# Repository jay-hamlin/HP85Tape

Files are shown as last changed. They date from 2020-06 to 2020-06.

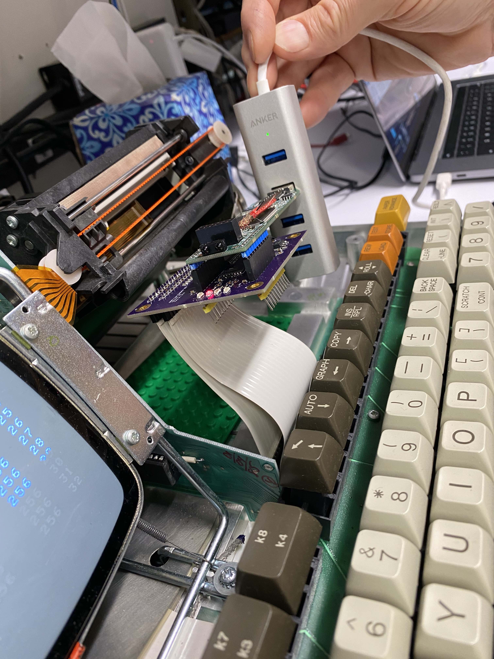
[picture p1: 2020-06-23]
documentation/inside2.jpg

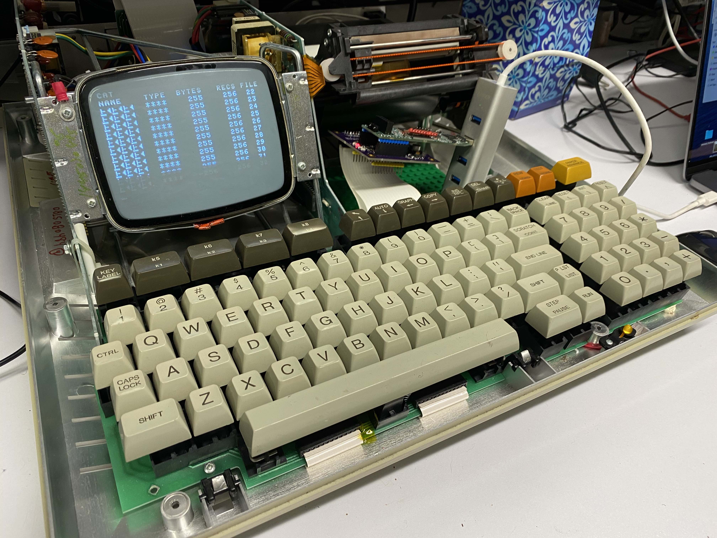
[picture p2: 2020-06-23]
documentation/inside_1.jpg

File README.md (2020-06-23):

PYTHON
 - command line: python3 hp85Main.py
 - edit hp85Uart.py with path of FTDI serial port.

FPGA
 - FPGA is Lattice iCE40HX1K-TQ144
 - Use Lattice ICEStick development board.
 - Editor is MS Visual Studio Code
 - Simulation with Mentor Graphics ModelSim "PE Student Edition"
 - Synthesis with LAttice iCECube2. Use Synplify Pro option.
 - Program FPGA with Lattice Diamond Programmer.

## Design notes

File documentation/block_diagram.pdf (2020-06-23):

Block Diagram

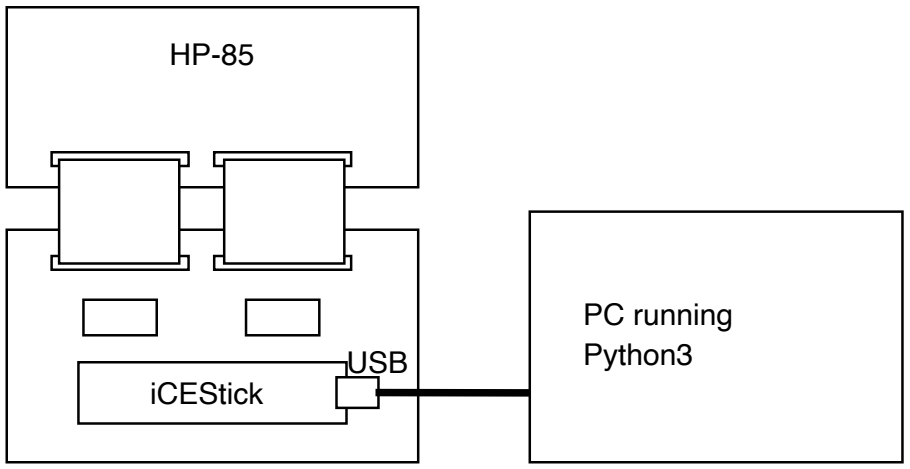
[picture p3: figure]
iCEStick; USB; PC running Python3

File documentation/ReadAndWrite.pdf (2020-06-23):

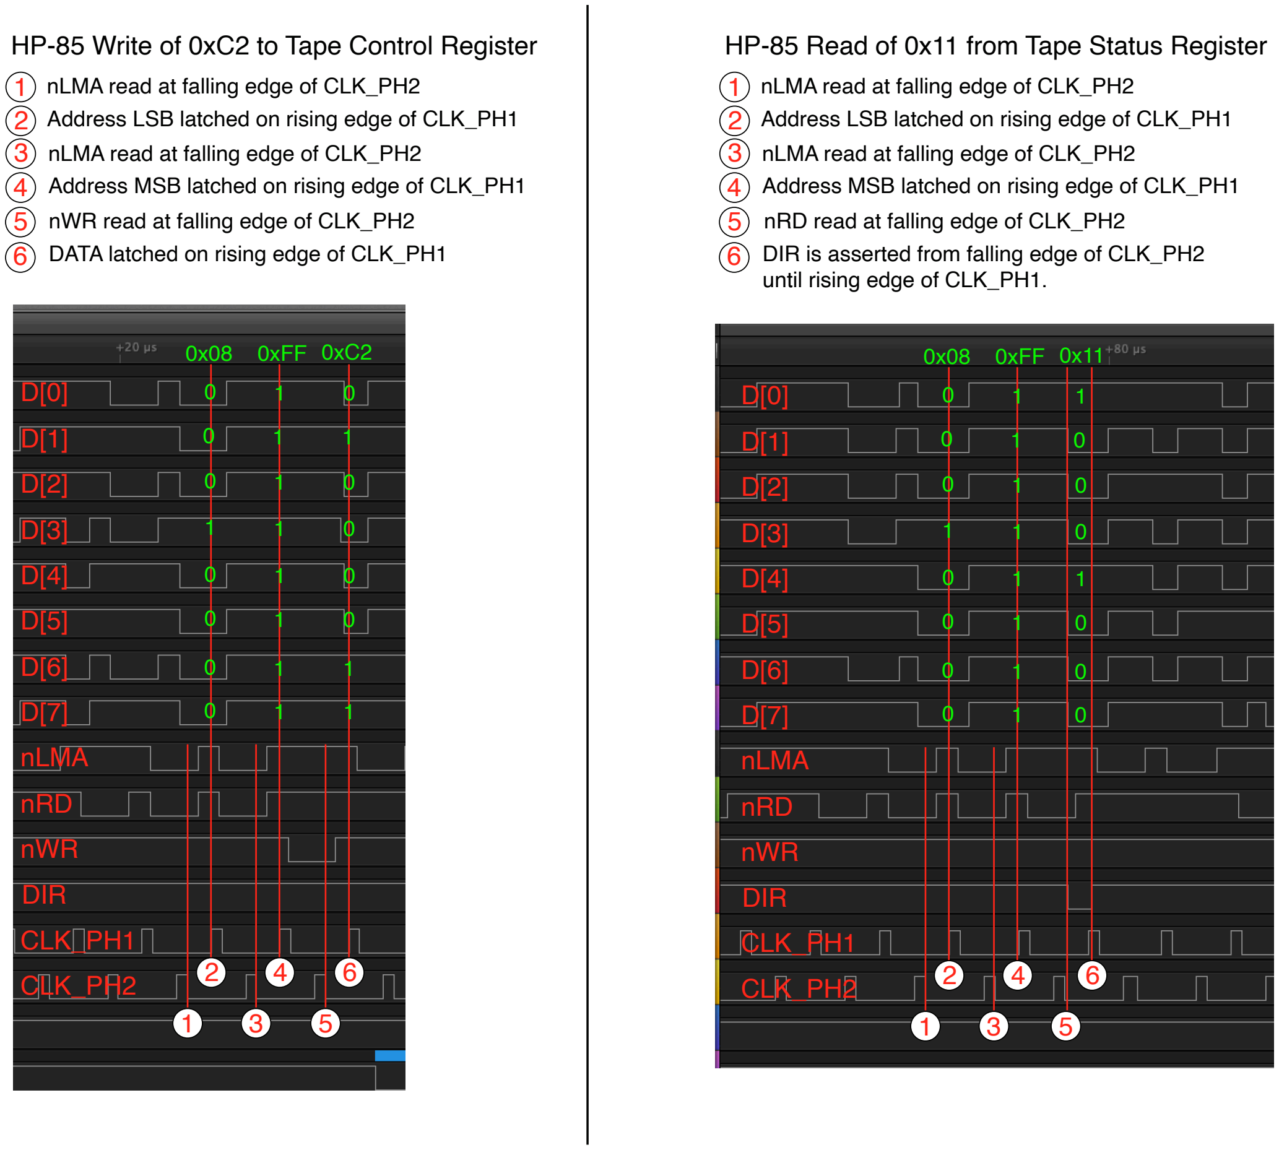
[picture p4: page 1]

### HP-85 Write of 0xC2 to Tape Control Register

1
2
3
4
5
6

nLMA read at falling edge of CLK_PH2
Address LSB latched on rising edge of CLK_PH1 nLMA read at falling edge of CLK_PH2
Address MSB latched on rising edge of CLK_PH1 nWR read at falling edge of CLK_PH2
DATA latched on rising edge of CLK_PH1

### HP-85 Read of 0x11 from Tape Status Register

1
2
3
4
5
6

nLMA read at falling edge of CLK_PH2
Address LSB latched on rising edge of CLK_PH1 nLMA read at falling edge of CLK_PH2
Address MSB latched on rising edge of CLK_PH1 nRD read at falling edge of CLK_PH2
DIR is asserted from falling edge of CLK_PH2 until rising edge of CLK_PH1.

D[0]

D[1]
D[2]

D[3]
D[4]
D[5]

D[6]
D[7]

### nLMA

### nRD

### nWR

### CLK_PH1

### CLK_PH2

### DIR

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
0x11

0

0x08 0xFF

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
D[0]

D[1]
D[2]

D[3]
D[4]
D[5]

D[6]
D[7]

### nLMA

### nRD

### nWR

### CLK_PH1

### CLK_PH2

### DIR

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
0xC2

1

0x08 0xFF

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
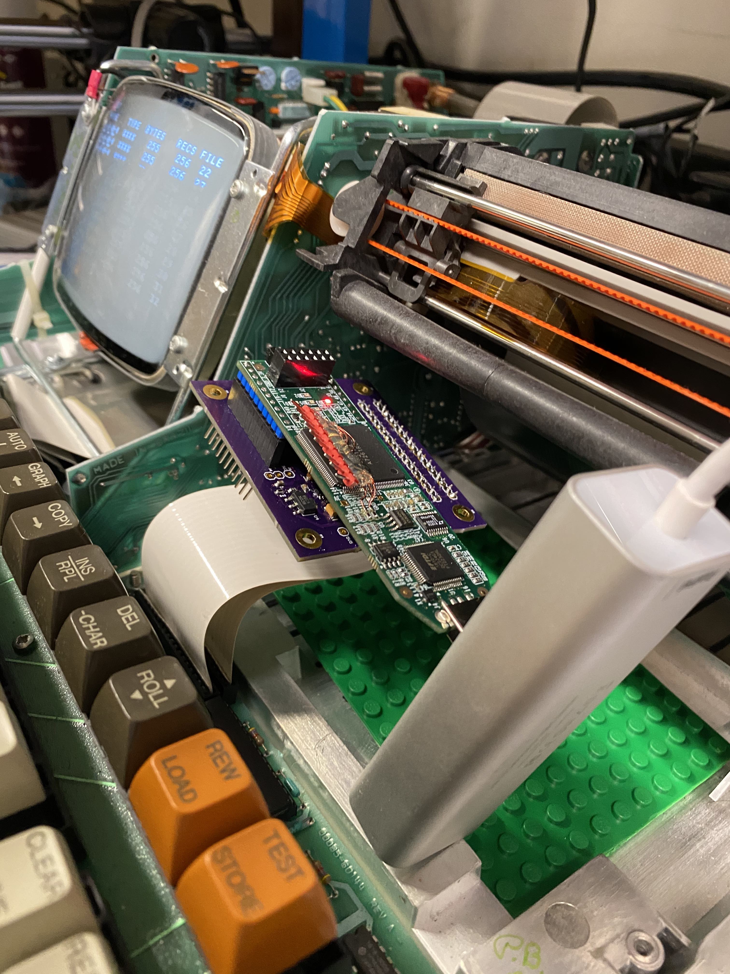
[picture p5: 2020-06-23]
documentation/inside3.jpg

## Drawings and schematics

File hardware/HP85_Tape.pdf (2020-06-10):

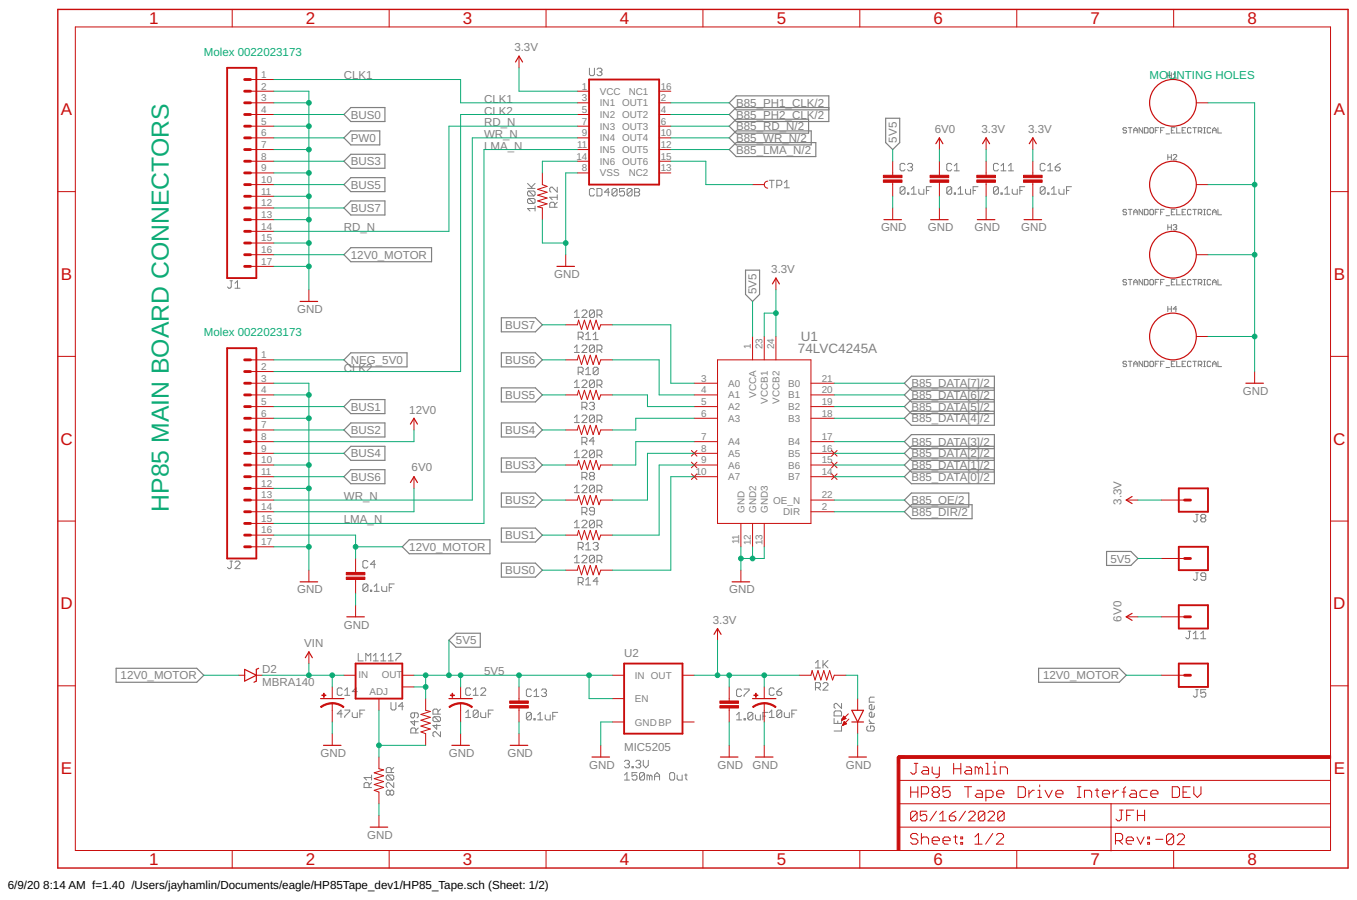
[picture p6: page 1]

6/9/20 8:14 AM f=1.40 /Users/jayhamlin/Documents/eagle/HP85Tape_dev1/HP85_Tape.sch (Sheet: 1/2)

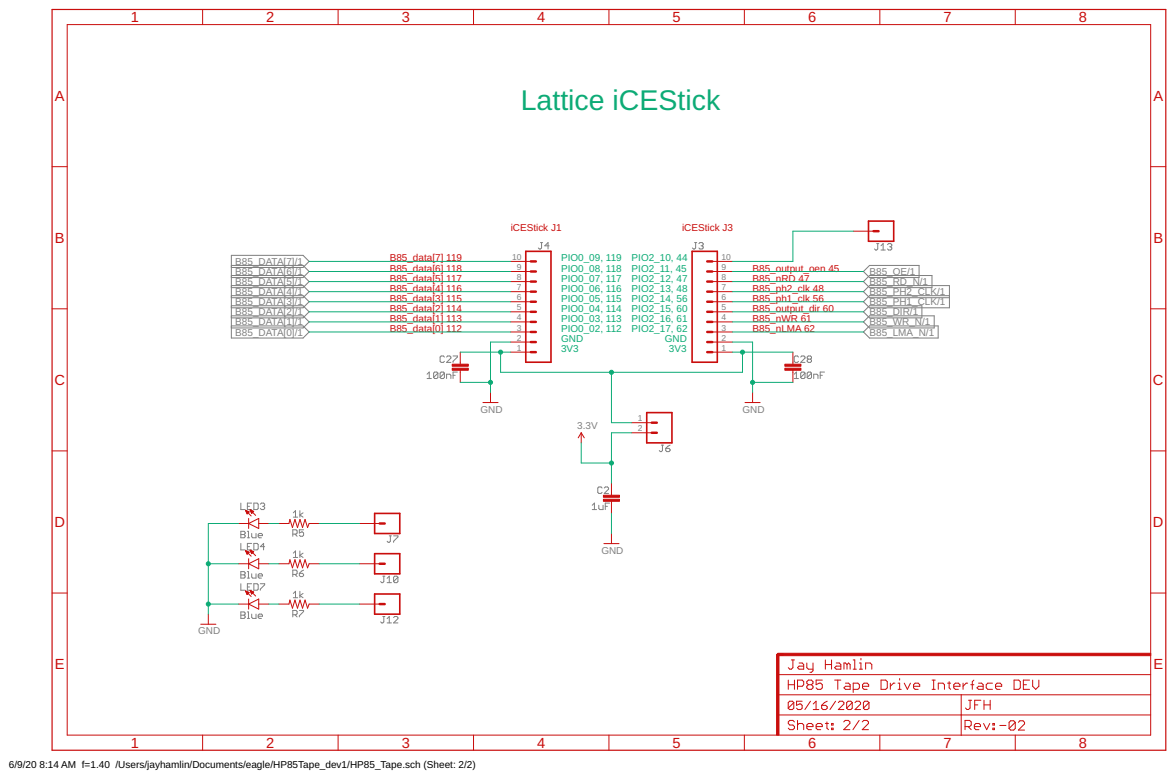
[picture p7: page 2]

6/9/20 8:14 AM f=1.40 /Users/jayhamlin/Documents/eagle/HP85Tape_dev1/HP85_Tape.sch (Sheet: 2/2)

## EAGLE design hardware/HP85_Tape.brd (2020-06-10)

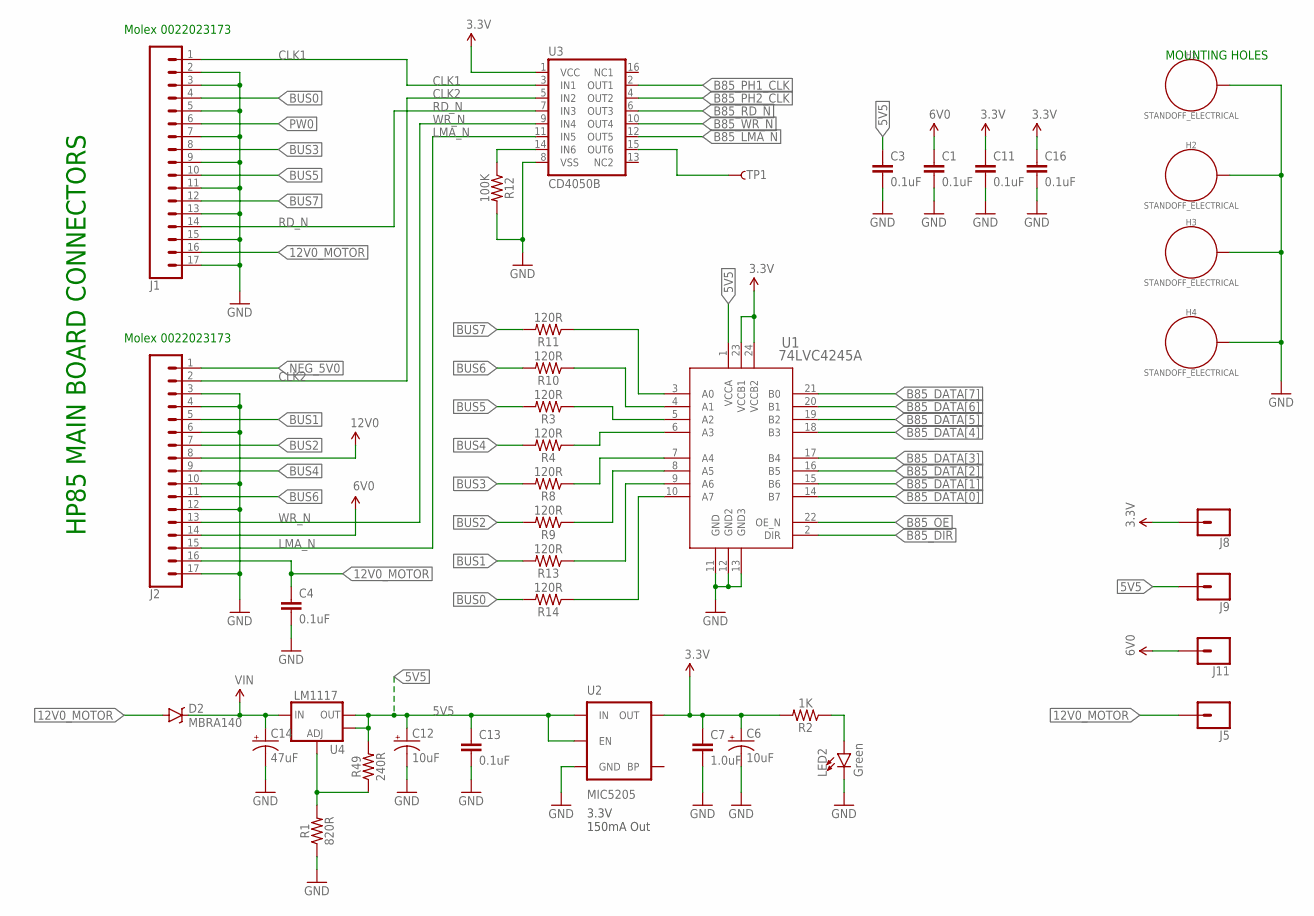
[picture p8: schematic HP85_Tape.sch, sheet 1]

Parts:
C1, C3, C4, C11, C13, C16: 0.1uF; 0603
C6, C12: 10uF; EIA3216
C7: 1.0uF; 0603
C14: 47uF; PANASONIC_D
D2: MBRA140; SMA-DIODE
H1, H2, H3, H4: STANDOFF_ELECTRICAL; STANDOFF-ELECTRICAL
J1, J2: CONN_17; 1X17
J5, J8, J9, J11: CONN_01; 1X01
LED2: Green; LED-1206
R1: 820R; 0603
R2: 1K; 0603
R3, R4, R8, R9, R10, R11, R13, R14: 120R; 0603
R12: 100K; 0603
R49: 240R; 0603
TP1: TP-3x5; PAD.03X.05
U1: 74LVC4245A; SO-24-M
U2: MIC5205; SOT23-5
U3: CD4050B; SO16
U4: LM1117; SOT223-ALT1

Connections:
3.3V: C6.+, C7.1, C11.1, C16.1, J8.1, R2.2, U1.23 (VCCB1), U1.24 (VCCB2), U2.5 (OUT), U3.1 (VCC); also elsewhere on the board
5V5: C3.1, C12.+, C13.1, J9.1, R49.2, U1.1 (VCCA), U2.1 (IN), U2.3 (EN), U4.2 (OUT), U4.4 (OUT)
6V0: C1.1, J2.14, J11.1
12V0: J2.8
12V0_MOTOR: C4.1, D2.A, J1.16, J2.16, J5.1
B85_DATA[0]: U1.14 (B7); also elsewhere on the board
B85_DATA[1]: U1.15 (B6); also elsewhere on the board
B85_DATA[2]: U1.16 (B5); also elsewhere on the board
B85_DATA[3]: U1.17 (B4); also elsewhere on the board
B85_DATA[4]: U1.18 (B3); also elsewhere on the board
B85_DATA[5]: U1.19 (B2); also elsewhere on the board
B85_DATA[6]: U1.20 (B1); also elsewhere on the board
B85_DATA[7]: U1.21 (B0); also elsewhere on the board
B85_DIR: U1.2 (DIR); also elsewhere on the board
B85_LMA_N: U3.12 (OUT5); also elsewhere on the board
B85_OE: U1.22 (OE_N); also elsewhere on the board
B85_PH1_CLK: U3.2 (OUT1); also elsewhere on the board
B85_PH2_CLK: U3.4 (OUT2); also elsewhere on the board
B85_RD_N: U3.6 (OUT3); also elsewhere on the board
B85_WR_N: U3.10 (OUT4); also elsewhere on the board
BUS0: J1.4, R14.2
BUS1: J2.5, R13.2
BUS2: J2.7, R9.2
BUS3: J1.8, R8.2
BUS4: J2.9, R4.2
BUS5: J1.10, R3.2
BUS6: J2.11, R10.2
BUS7: J1.12, R11.2
CLK1: J1.1, U3.3 (IN1)
CLK2: J2.2, U3.5 (IN2)
GND: C1.2, C3.2, C4.2, C6.-, C7.2, C11.2, C12.-, C13.2, C14.-, C16.2, H1.P1, H2.P1, H3.P1, H4.P1, J1.2, J1.3, J1.5, J1.7, J1.9, J1.11, J1.13, J1.15, J1.17, J2.3, J2.4, J2.6, J2.10, J2.12, J2.17, LED2.C, R1.1, R12.2, U1.11 (GND), U1.12 (GND2), U1.13 (GND3), U2.2 (GND), U3.8 (VSS); also elsewhere on the board
LMA_N: J2.15, U3.11 (IN5)
unnamed: LED2.A, R2.1
unnamed: R1.2, R49.1, U4.1 (ADJ)
unnamed: R12.1, U3.14 (IN6)
unnamed: R14.1, U1.10 (A7)
unnamed: TP1.P$1, U3.15 (OUT6)
unnamed: R13.1, U1.9 (A6)
unnamed: R9.1, U1.8 (A5)
unnamed: R8.1, U1.7 (A4)
unnamed: R4.1, U1.6 (A3)
unnamed: R3.1, U1.5 (A2)
unnamed: R10.1, U1.4 (A1)
unnamed: R11.1, U1.3 (A0)
NEG_5V0: J2.1
PW0: J1.6
RD_N: J1.14, U3.7 (IN3)
VIN: C14.+, D2.C, U4.3 (IN)
WR_N: J2.13, U3.9 (IN4)

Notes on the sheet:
3.3V 150mA Out
HP85 MAIN BOARD CONNECTORS
MOUNTING HOLES
Molex 0022023173

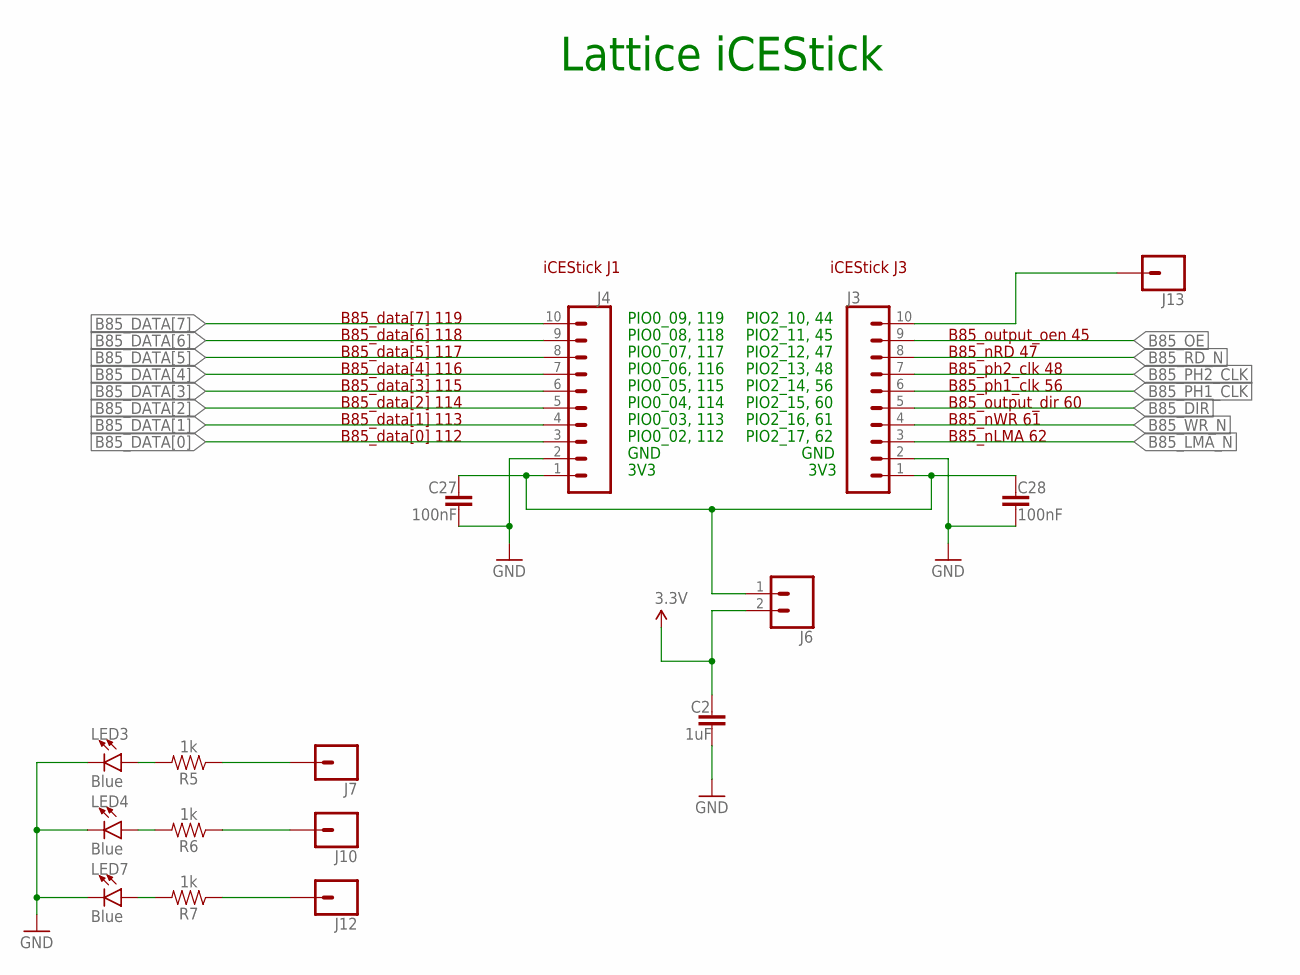
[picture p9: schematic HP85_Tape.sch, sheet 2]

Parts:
C2: 1uF; 0603
C27, C28: 100nF; 0603
J3, J4: CONN_10"; 1X10
J6: CONN_02; 1X02
J7, J10, J12, J13: CONN_01; 1X01
LED3, LED4, LED7: Blue; LED-1206
R5, R6, R7: 1k; 0603

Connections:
3.3V: C2.1, J6.2; also elsewhere on the board
B85_DATA[0]: J4.3; also elsewhere on the board
B85_DATA[1]: J4.4; also elsewhere on the board
B85_DATA[2]: J4.5; also elsewhere on the board
B85_DATA[3]: J4.6; also elsewhere on the board
B85_DATA[4]: J4.7; also elsewhere on the board
B85_DATA[5]: J4.8; also elsewhere on the board
B85_DATA[6]: J4.9; also elsewhere on the board
B85_DATA[7]: J4.10; also elsewhere on the board
B85_DIR: J3.5; also elsewhere on the board
B85_LMA_N: J3.3; also elsewhere on the board
B85_OE: J3.9; also elsewhere on the board
B85_PH1_CLK: J3.6; also elsewhere on the board
B85_PH2_CLK: J3.7; also elsewhere on the board
B85_RD_N: J3.8; also elsewhere on the board
B85_WR_N: J3.4; also elsewhere on the board
GND: C2.2, C27.2, C28.2, J3.2, J4.2, LED3.C, LED4.C, LED7.C; also elsewhere on the board
unnamed: LED3.A, R5.2
unnamed: LED4.A, R6.2
unnamed: LED7.A, R7.2
unnamed: J12.1, R7.1
unnamed: C27.1, C28.1, J3.1, J4.1, J6.1
unnamed: J10.1, R6.1
unnamed: J7.1, R5.1
unnamed: J3.10, J13.1

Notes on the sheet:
Lattice iCEStick
3V3
GND
PIO0_02, 112
PIO0_03, 113
PIO0_04, 114
PIO0_05, 115
PIO0_06, 116
PIO0_07, 117
PIO0_08, 118
PIO0_09, 119
PIO2_10, 44
PIO2_11, 45
PIO2_12, 47
PIO2_13, 48
PIO2_14, 56
PIO2_15, 60
PIO2_16, 61
PIO2_17, 62
iCEStick J1
iCEStick J3
B85_data[7] 119
B85_nLMA 62
B85_nWR 61
B85_data[6] 118
B85_data[1] 113
B85_data[5] 117
B85_ph1_clk 56
B85_data[0] 112
B85_data[4] 116
B85_output_dir 60
B85_data[3] 115
B85_ph2_clk 48
B85_data[2] 114
B85_output_oen 45
B85_nRD 47

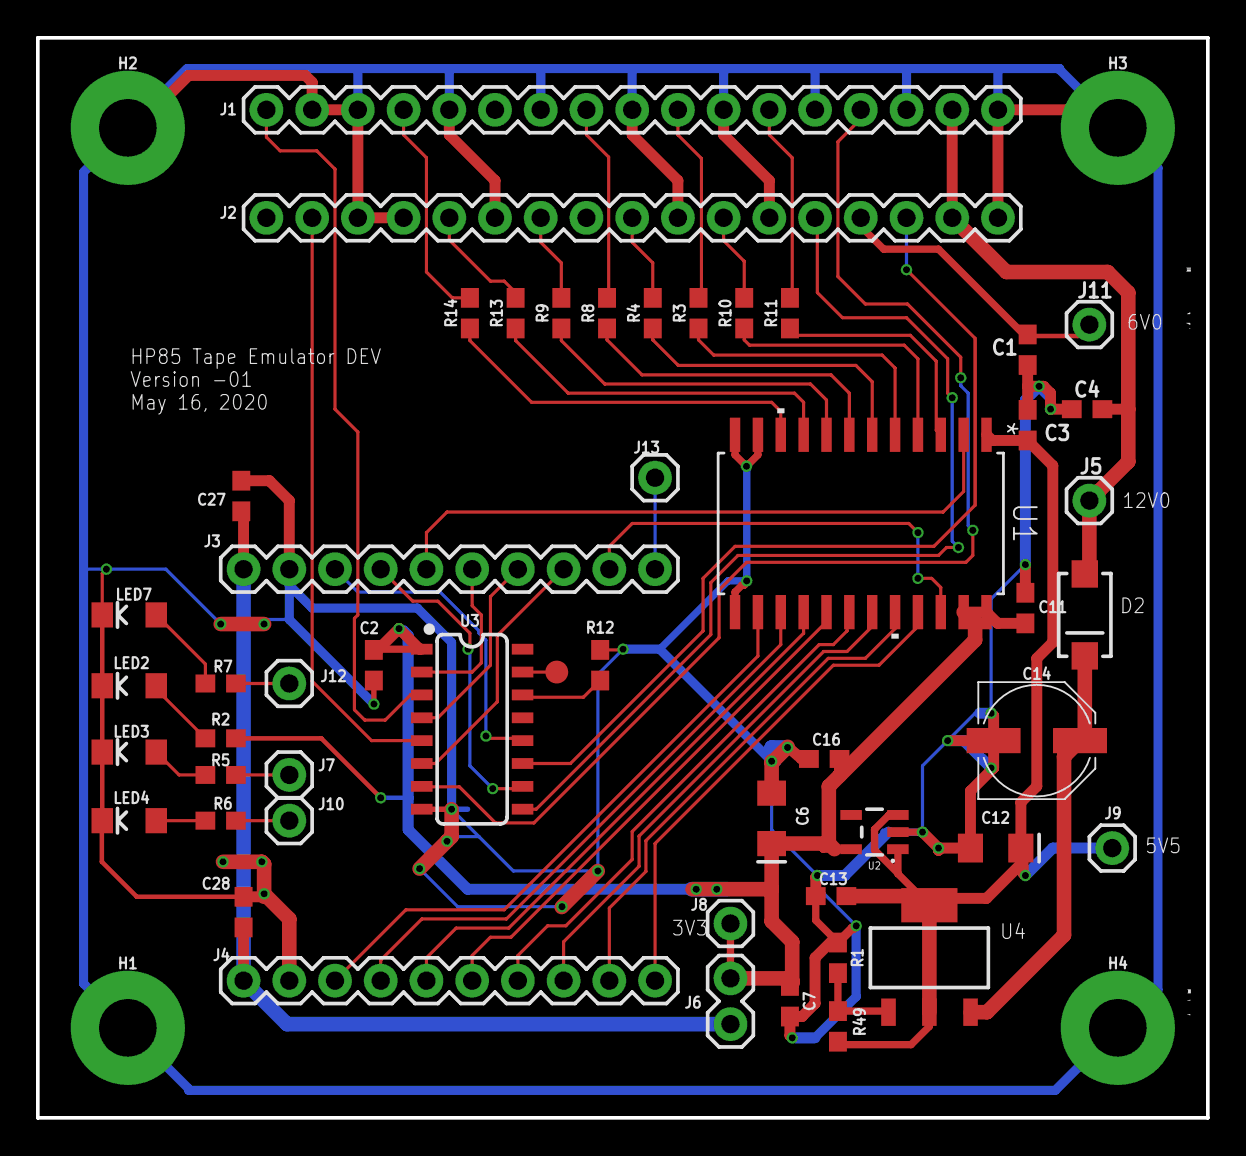
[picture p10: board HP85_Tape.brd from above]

Board: 2 copper layers, 65.0 x 60.0 mm, 55 parts (0 on the bottom side), 54 nets.

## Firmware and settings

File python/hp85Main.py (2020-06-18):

 ## obdMain.py
## obdCommunications test app
##
## Created: 3/8/19 07:00:00 AM
## Author :Jay Hamlin
##

import sys
import time
import select
import tty
import termios

import hp85Header  as header
import hp85Utilities  as utility
import hp85Transport as transport
import hp85Uart as uart
import hp85PktDecoder as packet

## global variables
kbdChoice = 0
serialport = 0

HP85_BAUD_RATE = 115200
HP85_PORT_NAME = "/dev/tty.usbserial-144101"

## A bunch of local functions...

def isData():
    return select.select([sys.stdin], [], [], 0) == ([sys.stdin], [], [])

def printMenu():
    print (30 * '-')
    print ("   M A I N - M E N U")
    print (30 * '-')
    print (" t. cartridge in/out")
    print (" s. read status")
    print (" c. read control")
    print (30 * '-')

    ch = ""
    while(ch == ""):
        if isData():
            ch = sys.stdin.read(1)
        else:
            time.sleep(0.050)

    return(ch);

##  PROGRAM MAIN LOOP STARTS HERE
serialport = uart.openSerialPort(HP85_BAUD_RATE,HP85_PORT_NAME)

transport.TapeTransportInit()

tachSpeed = 0

while (uart.keepLooping ==1):
    kbdChoice = printMenu()
    transport.printTransportStats()

    if kbdChoice == 'r':  ## reset
        transport.tapePosition = (32*100)
        transport.TapeTransportInit()
 
    if kbdChoice == 'c':  ## read control register
        uart.WritePacketAndEcho(header.PKT_RD_CONTROL,0x00)        
            
    if kbdChoice == 'z':  ## rewind
            packet.PacketDecoder(0x43,0x16)
    if kbdChoice == 'y':  ## stop
            packet.PacketDecoder(0x43,0x00)

    if kbdChoice == 'x' or kbdChoice == 'X':
        uart.keepLooping = 0
        print ("Exiting...")
        time.sleep(0.050)

##  PROGRAM MAIN LOOP ENDS HERE
serialport.close()
sys.exit()

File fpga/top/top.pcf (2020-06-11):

# ##############################################################################

# iCEcube PCF

# Version:            2017.08.27940

# File Generated:     May 12 2020 15:15:45

# Family & Device:    iCE40HX1K

# Package:            TQ144

# ##############################################################################

###IOSet List 22
set_io B85_data[7] 119
set_io B85_nLMA 62
set_io B85_nWR 61
set_io B85_nRD 47
set_io led_3 97
set_io B85_data[6] 118
set_io B85_data[1] 113
set_io B85_data[5] 117
set_io B85_ph1_clk 56
set_io led_1 99
set_io led_5 95
set_io rst_button 90 -pullup yes
set_io uart_rx 9
set_io B85_data[0] 112
set_io B85_data[4] 116
set_io B85_output_oen 45
set_io B85_output_dir 60
set_io led_2 98
set_io B85_data[3] 115
set_io B85_ph2_clk 48
set_io clk 21
set_io uart_tx 8
set_io B85_data[2] 114
set_io led_4 96
set_io J13_test_point 44

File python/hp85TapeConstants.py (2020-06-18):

##
## Created: 3/8/19 07:00:00 AM
## Author :Jay Hamlin
##

LOOPS_PER_INCH = 32

TAPE_LENGTH_IN_FEET = 140.00
TAPE_LENGTH_IN_INCHES = (TAPE_LENGTH_IN_FEET*12.00)

## the tape length in loop counts at slow speed, high speed will be 1/6 of this
TAPE_LENGTH_IN_LOOPS = int(TAPE_LENGTH_IN_INCHES*LOOPS_PER_INCH) ## 140*12*320

TAPE_HOLE_WIDTH_IN_INCHES = 0.026  ## HP Journal, May 1976, page 9
TAPE_HOLE_WIDTH_IN_LOOPS = int(TAPE_HOLE_WIDTH_IN_INCHES*LOOPS_PER_INCH) ## 8

HOLE_PAIR_SPACE_IN_LOOPS = int(0.218*LOOPS_PER_INCH) ## 69

## See HP Journal, May 1976, page 9
##  BOT == Begining of Tape
##  EOT == End of Tape
##  Holes at the begining of the tape
##    There are 3 pairs of holes at the begining of the tape
##      pairs are at 24", 36" and 48"
##      holes within a pair are spaced 0.218" apart
##    And the Load Point hole at 72"
BOT_HOLE_P1_A = (24*LOOPS_PER_INCH)  ## BOT pair 1, hole A
BOT_HOLE_P1_B = (BOT_HOLE_P1_A + HOLE_PAIR_SPACE_IN_LOOPS) ## BOT pair 1, hole B
BOT_HOLE_P2_A = (36*LOOPS_PER_INCH)  ## BOT pair 1, hole A
BOT_HOLE_P2_B = (BOT_HOLE_P2_A + HOLE_PAIR_SPACE_IN_LOOPS) ## BOT pair 2, hole B
BOT_HOLE_P3_A = (48*LOOPS_PER_INCH)  ## BOT pair 1, hole A
BOT_HOLE_P3_B = (BOT_HOLE_P3_A + HOLE_PAIR_SPACE_IN_LOOPS) ## BOT pair 3, hole B
BOT_HOLE_LOAD_POINT = (72*LOOPS_PER_INCH)
##  Holes at the end of the tape
##    There are 4 holes at the end of the tape
##       (EOT-24"),(EOT-36"),(EOT-48"),(EOT-72")
##       The -72" hole is called the early warning hole.
EOT_HOLE_EARLY_WARNING = (TAPE_LENGTH_IN_LOOPS-(72*LOOPS_PER_INCH))
EOT_HOLE_C = (TAPE_LENGTH_IN_LOOPS-(48*LOOPS_PER_INCH))
EOT_HOLE_B = (TAPE_LENGTH_IN_LOOPS-(36*LOOPS_PER_INCH))
EOT_HOLE_A = (TAPE_LENGTH_IN_LOOPS-(24*LOOPS_PER_INCH))

tapeHoleArray = [BOT_HOLE_P1_A,\
                BOT_HOLE_P1_B,\
                BOT_HOLE_P2_A,\
                BOT_HOLE_P2_B,\
                BOT_HOLE_P3_A,\
                BOT_HOLE_P3_B,\
                BOT_HOLE_LOAD_POINT,\
                EOT_HOLE_EARLY_WARNING,\
                EOT_HOLE_C,\
                EOT_HOLE_B,\
                EOT_HOLE_A]
tapeHoleArraySize = 11

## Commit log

2020-06-10 Project setup
    [HP85_Tape.brd, HP85_Tape.sch]
2020-06-10 fixed hdr bug, header
    [hp85Main.py]
2020-06-15 added protocol HOLE commands and fixed tachometer timing
2020-06-17 added hole command

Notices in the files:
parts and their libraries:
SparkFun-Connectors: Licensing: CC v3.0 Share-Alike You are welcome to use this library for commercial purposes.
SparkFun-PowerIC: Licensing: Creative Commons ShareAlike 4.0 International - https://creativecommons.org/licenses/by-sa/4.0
